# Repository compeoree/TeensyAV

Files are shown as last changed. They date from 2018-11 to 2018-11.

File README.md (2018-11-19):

# TeensyAV
A two-layer printed circuit board that breaks out a Teensy 3.5 or 3.6. Its primary goal is to provide a front end for the [Teensy Convolution Sofware Defined Radio](https://github.com/compeoree/Teensy-ConvolutionSDR), but can be used for any audio/video project. 
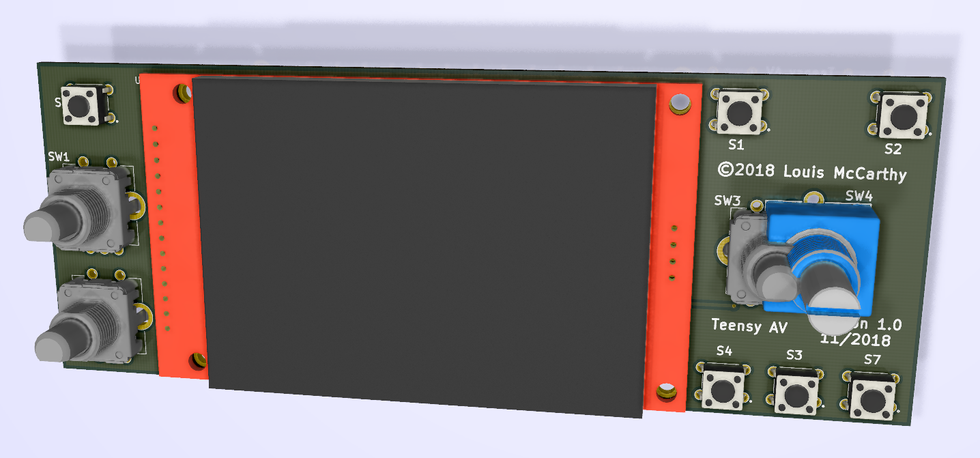
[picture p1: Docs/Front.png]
front Front View

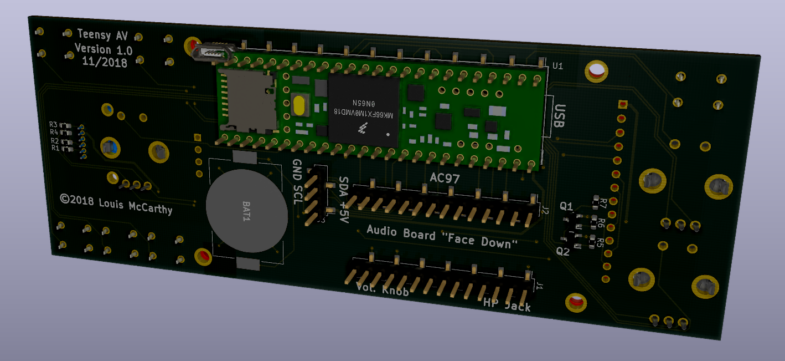
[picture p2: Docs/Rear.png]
back Back View


# UNTESTED!
This is a work in progress and has yet to be fabricated, assembled, or tested.

# Easy Method
* Order PCB through [OSHPark](https://oshpark.com/shared_projects/IBIkLilf)

# DIY Method
* Install KiCad version 5 (http://kicad-pcb.org/download/)
* Copy Library and Modules to KiCad install directory (usually {install_location}/KiCad/share/kicad/)
* Open TeensyAV.pro project file

## BOM (Total price approximately $90)
* PCB ([$18.68](https://oshpark.com/shared_projects/IBIkLilf))
* U1 Teensy 3.6 ([$29.25](https://www.pjrc.com/store/teensy36.html))
* J1 Audio Board ([$14.25](https://www.pjrc.com/store/teensy3_audio.html))
* U2 Touchscreen ([$15.00](https://www.pjrc.com/store/display_ili9341_touch.html))
* Q1 Si2371EDS MOSFET ([$0.49](https://www.mouser.com/ProductDetail/78-SI2371EDS-T1-GE3))
* Q2 BSR802N MOSFET ([$0.46](https://www.mouser.com/ProductDetail/726-BSR802NL6327))
* S1,S2,S3,S4,S5,S7 Switches ([$0.25](https://www.mouser.com/ProductDetail/653-B3F-1000))
* SW1,SW2,SW3 Magnetic Encoder ([$1.14](https://www.mouser.com/ProductDetail/858-EN12-HS22AF20))
* SW4 Optional Optical Encoder ([$28.30](https://www.mouser.com/ProductDetail/652-EM14A0D-B28L064N))
* R1,R2,R3,R4 10K SMD Resistor ([$0.10](https://www.mouser.com/ProductDetail/603-RC0603FR-0710KL))
* CR2032 RTC Battery and Holder ([$0.29](https://www.mouser.com/ProductDetail/712-BAT-HLD-001))
* J1,J2 SMD male headers ([$2.10](https://www.mouser.com/ProductDetail/710-61001418221))
* U1 SMD male headers (left) ([$3.61](https://www.mouser.com/ProductDetail/710-61002418221))

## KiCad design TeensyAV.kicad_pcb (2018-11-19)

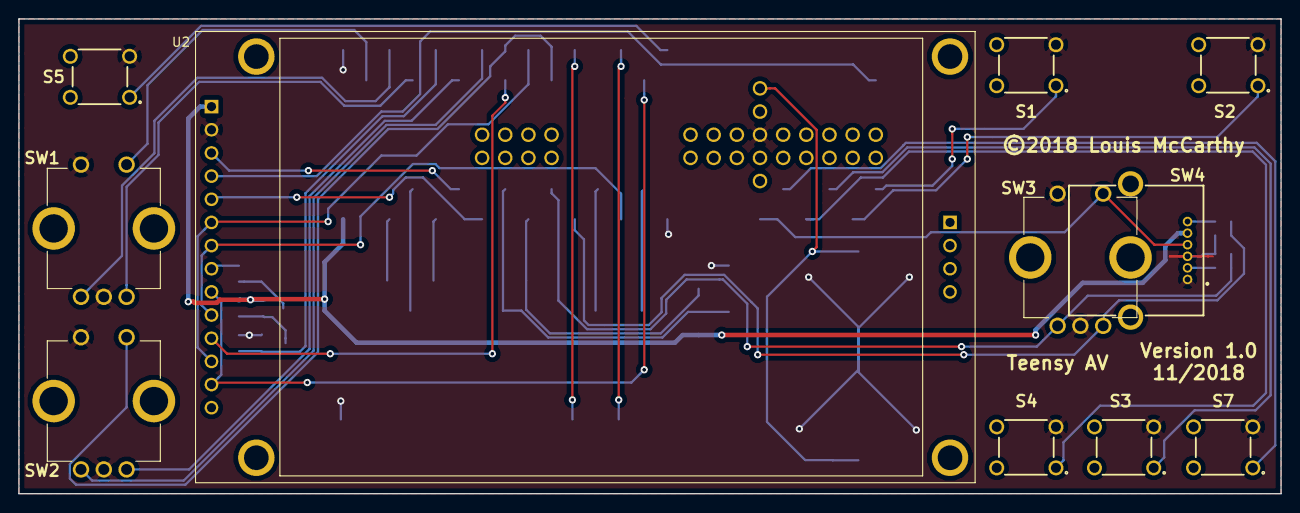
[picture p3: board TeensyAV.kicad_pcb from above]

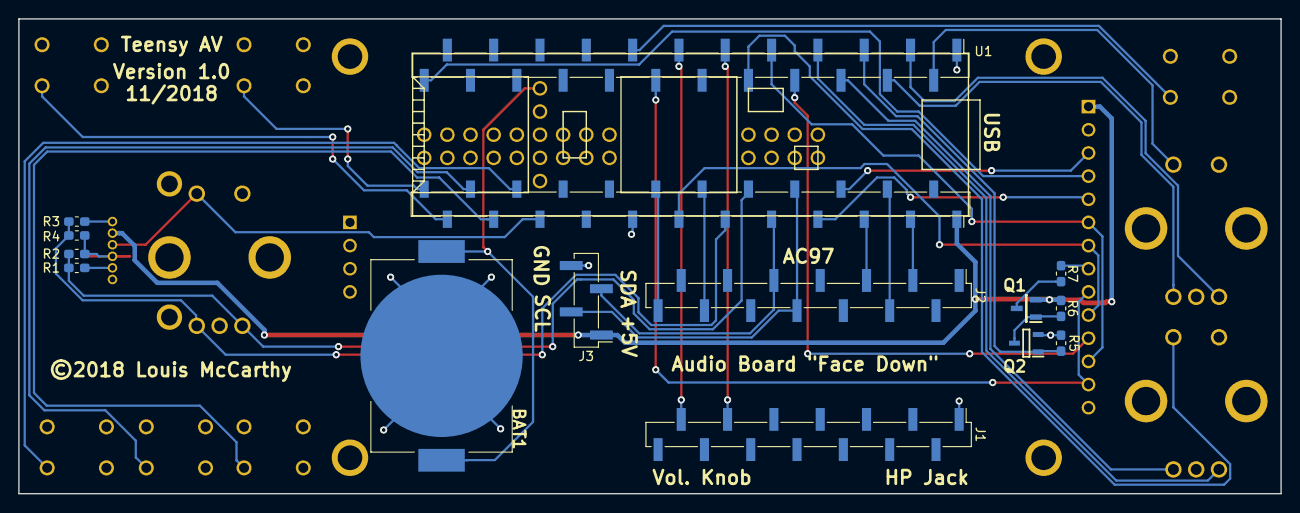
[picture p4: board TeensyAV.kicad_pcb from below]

Board: 2 copper layers, 138.4 x 52.1 mm, 25 parts (14 on the bottom side), 40 nets.

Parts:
BAT1: BAT-HLD-001; BATHLD001
J1, J2: Conn_01x14_Male; PinHeader_1x14_P2.54mm_Vertical_SMD_Pin1Left
J3: Conn_01x04_Male; PinHeader_1x04_P2.54mm_Vertical_SMD_Pin1Left
Q1: SI2371EDS-T1-GE3; SOT95P237X112-3N
Q2: BSR802N_L6327; SOT95P285X120-3N
R1, R2, R3, R4, R5, R6: 10K; R_0603_1608Metric_Pad1.05x0.95mm_HandSolder
R7: 100R; R_0603_1608Metric_Pad1.05x0.95mm_HandSolder
S1, S2, S3, S4, S5, S7: B3F-1000; B3F1002
SW1, SW2, SW3: EN12-HS22AF20; EN12HS22AF20
SW4: EM14A0D-C24-L064S; EM14A0D(AXIAL)
U1: Teensy3.6; Teensy35_36_SMD
U2: ILI9341_TOUCH

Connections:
+3V3: J2.3, U1.51
+5V: J3.1, Q1.2, R6.2, SW4.5, U1.53, U2.1
/Backlight: Q2.1, R5.2, U1.5
B1: S1.1, U1.30
B2: S2.1, U1.31
B3: S3.1, U1.32
B4: S4.1, U1.33
B5: SW3.E1, SW4.4, U1.35
B7: S7.1, U1.34
BCLK: J1.11, U1.11
GND: BAT1.3, J1.1, J3.4, Q2.2, R2.2, R4.2, R5.1, S1.3, S2.3, S3.3, S4.3, S5.3, S7.3, SW1.C1, SW1.D1, SW2.C1, SW2.D1, SW3.C1, SW3.D1, SW4.1, SW4.3, U1.1, U1.27, U1.39, U2.2
LRCLK: J2.4, U1.50
MCLK: J1.13, U1.13
MISO: U1.14, U2.9, U2.13
MOSI: U1.9, U2.6, U2.12
unnamed: BAT1.1, BAT1.2, U1.25
unnamed: Q1.1, Q2.3, R6.1
unnamed: Q1.3, R7.1
unnamed: R1.1, SW4.2
unnamed: R1.2, R2.1, SW3.A1, U1.44
unnamed: R3.1, SW4.6
unnamed: R3.2, R4.1, SW3.B1, U1.43
unnamed: R7.2, U2.8
unnamed: SW1.A1, U1.3
unnamed: SW1.B1, U1.4
unnamed: SW1.E1, U1.2
unnamed: SW2.A1, U1.7
unnamed: SW2.B1, U1.6
unnamed: SW2.E1, U1.10
PWR: S5.1, U1.15
RX: J2.14, U1.40
SCL: J2.8, J3.2, U1.46
SCLK: U1.41, U2.7, U2.10
SDA: J2.9, J3.3, U1.45
TFT_CS: U1.48, U2.3
TFT_DC: U1.47, U2.5
TFT_RST: U1.24, U2.4
TX: J2.5, U1.49
T_CS: U1.8, U2.11
VOL: J2.12, U1.42

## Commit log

2018-11-19 Initial files added
    [TeensyAV.kicad_pcb, TeensyAV.sch]
2018-11-19 Updated BOM and added images
2018-11-19 Updated BOM

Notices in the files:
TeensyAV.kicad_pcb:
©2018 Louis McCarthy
